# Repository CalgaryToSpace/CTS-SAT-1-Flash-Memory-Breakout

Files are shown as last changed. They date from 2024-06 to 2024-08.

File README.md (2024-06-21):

# CTS-SAT-1-Flash-Memory-Breakout

A breakout board for the CTS-SAT-1 flash memory module, used on the Onboard Computer (OBC) of the CTS-SAT-1 satellite.

The target memory modules is the `S70FL01GSAGMFI011` (`S70FL01`). This PCB is compatible with many similar memory modules in the same family.

This PCB is pin-compatible with the following memory modules:
* Infineon `S70FL01GSAGMFI011` (`S70FL01`)
* Infineon `S25FL512SDVFG1` (`S25FL512`)
* Cypress `25HL01GTFI01` (`25HL01`)

## PCB Renderings

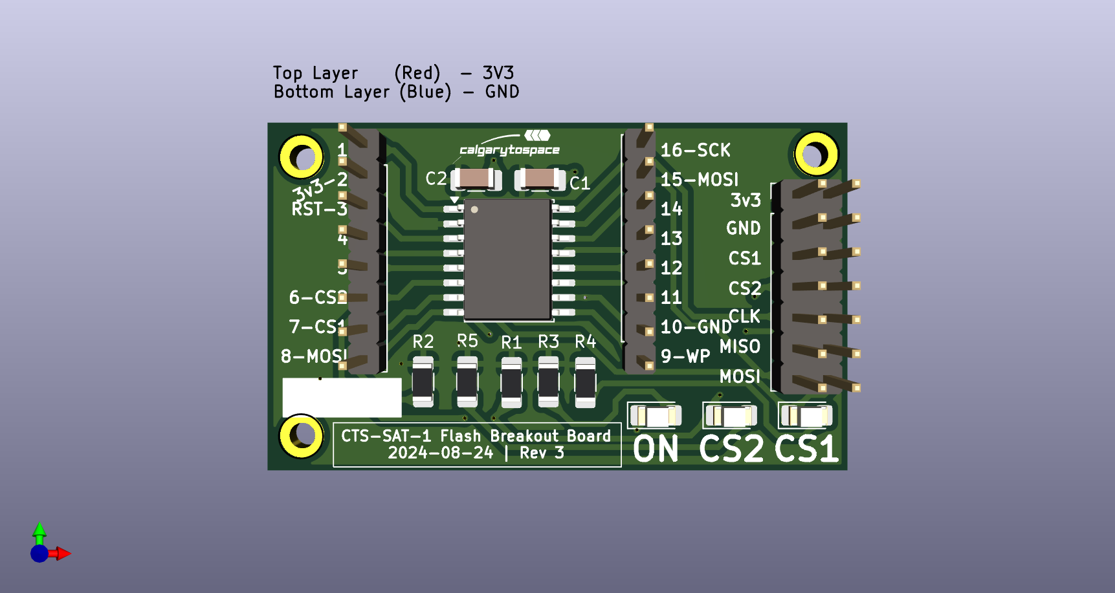
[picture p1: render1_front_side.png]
Front Rendering


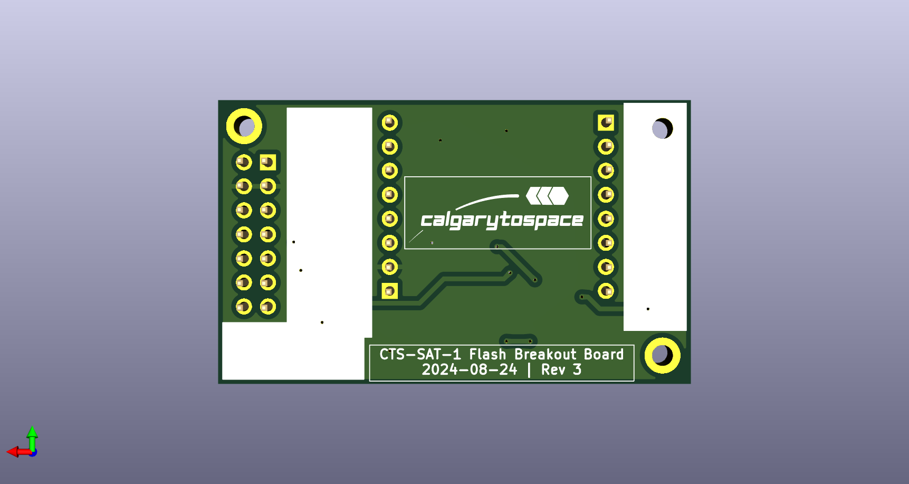
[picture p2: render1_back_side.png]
Back Rendering


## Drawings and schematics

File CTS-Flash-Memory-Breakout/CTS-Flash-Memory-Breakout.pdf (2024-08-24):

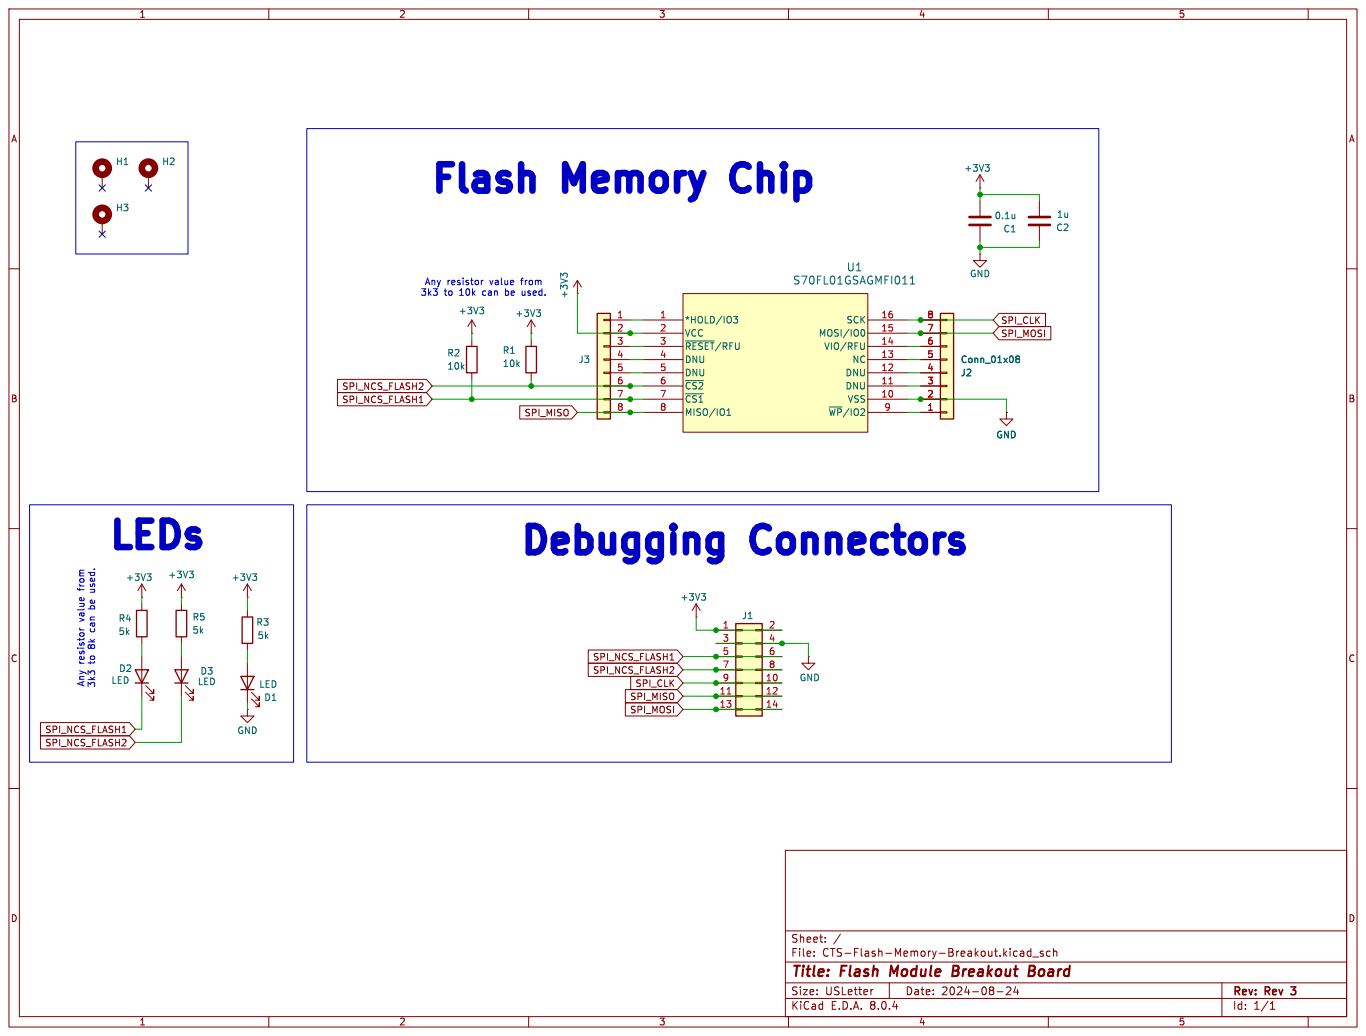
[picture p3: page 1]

2 | 7 7
3 | 6 6
4 | 5 5
5 | 4 4
6 | 3 3
7 | 2 2
8 | 1 1

SPI_NCS_FLASH2 SPI_NCS_FLASH2 SPI_NCS_FLASH1 Any resistor value from 3k3 to 8k can be used.

File: CTS-Flash-Memory-Breakout.kicad_sch Sheet: / GND

Id: 1/1 Title: Flash Module Breakout Board

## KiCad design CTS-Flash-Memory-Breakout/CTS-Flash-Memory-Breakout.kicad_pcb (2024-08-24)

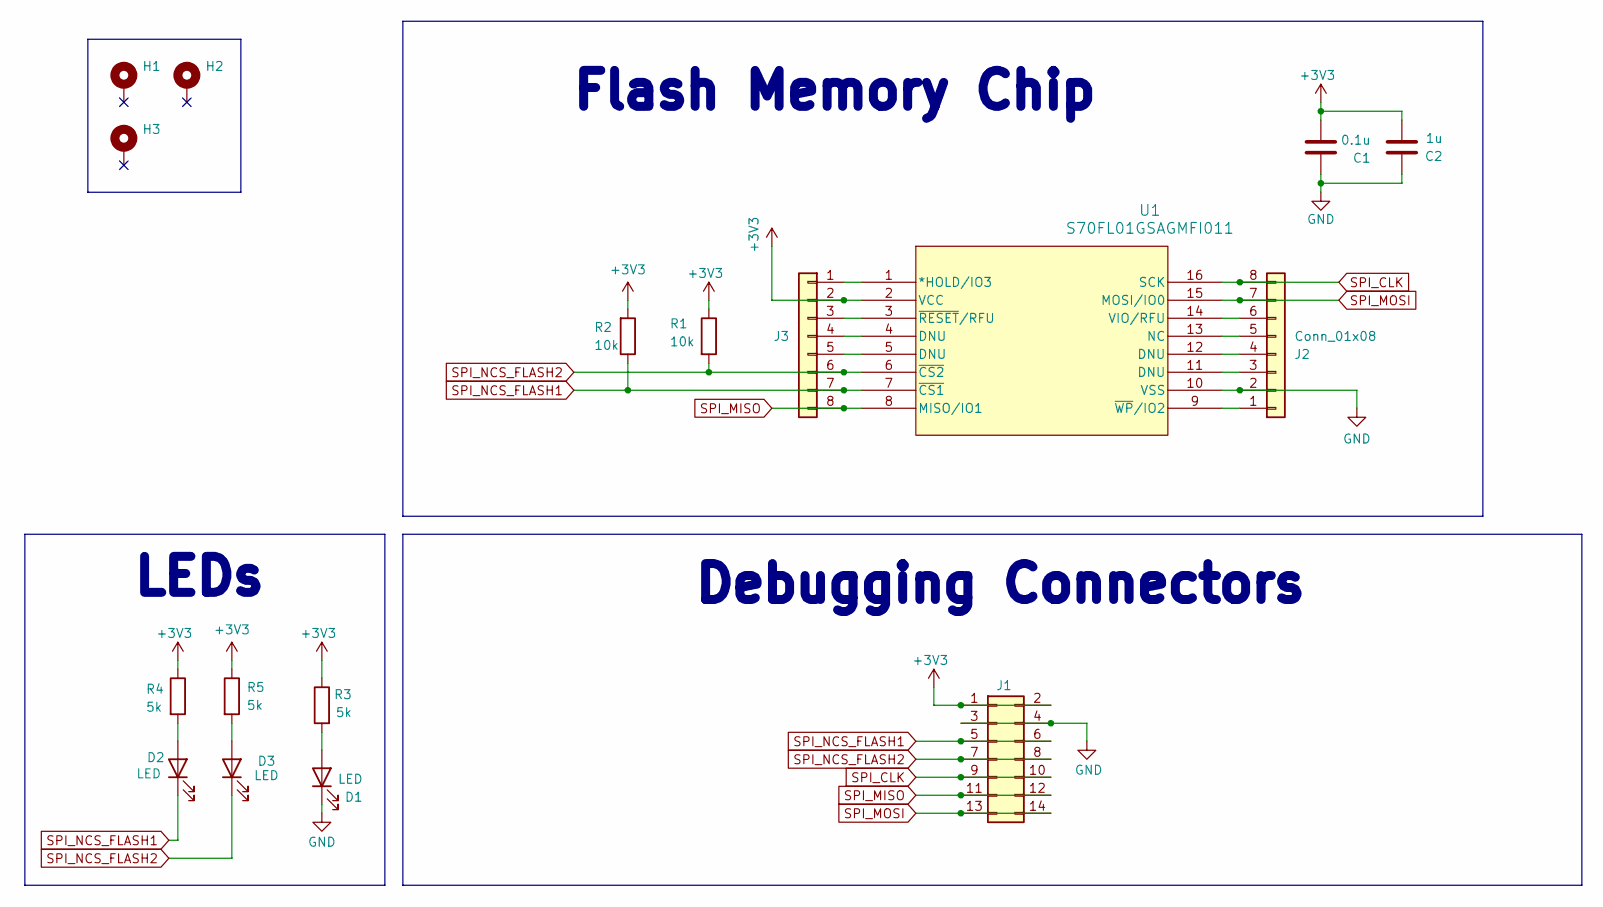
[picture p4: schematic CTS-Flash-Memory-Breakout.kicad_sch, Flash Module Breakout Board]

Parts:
C1: 0.1u; C_1206_3216Metric_Pad1.33x1.80mm_HandSolder
C2: 1u; C_1206_3216Metric_Pad1.33x1.80mm_HandSolder
D1, D2, D3: LED; LED_1206_3216Metric_Pad1.42x1.75mm_HandSolder
H1, H2, H3: MountingHole_Pad; MountingHole_2.2mm_M2_DIN965_Pad
J1: Conn_02x07_Counter_Clockwise; PinHeader_2x07_P2.54mm_Vertical
J2, J3: Conn_01x08; PinHeader_1x08_P2.54mm_Vertical
R1, R2: 10k; R_1206_3216Metric_Pad1.30x1.75mm_HandSolder
R3, R4, R5: 5k; R_1206_3216Metric_Pad1.30x1.75mm_HandSolder
U1: S70FL01GSAGMFI011; SOIC-16W_7.5x10.3mm_P1.27mm

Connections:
+3V3: C1.2, C2.2, J1.1, J1.2, J3.2, R1.1, R2.2, R3.1, R4.1, R5.1, U1.2 (VCC)
GND: C1.1, C2.1, D1.1 (K), J1.3, J1.4, J2.2, U1.10 (VSS)
unnamed: D1.2 (A), R3.2
unnamed: D2.2 (A), R4.2
unnamed: D3.2 (A), R5.2
unnamed: J2.1, U1.9 (~WP/IO2)
unnamed: J2.3, U1.11 (DNU)
unnamed: J2.4, U1.12 (DNU)
unnamed: J2.5, U1.13 (NC)
unnamed: J2.6, U1.14 (VIO/RFU)
unnamed: J3.1, U1.1 (*HOLD/IO3)
unnamed: J3.3, U1.3 (~RESET/RFU)
unnamed: J3.4, U1.4 (DNU)
unnamed: J3.5, U1.5 (DNU)
SPI_CLK: J1.9, J1.10, J2.8, U1.16 (SCK)
SPI_MISO: J1.11, J1.12, J3.8, U1.8 (MISO/IO1)
SPI_MOSI: J1.13, J1.14, J2.7, U1.15 (MOSI/IO0)
SPI_NCS_FLASH1: D2.1 (K), J1.5, J1.6, J3.7, R2.1, U1.7 (~CS1)
SPI_NCS_FLASH2: D3.1 (K), J1.7, J1.8, J3.6, R1.2, U1.6 (~CS2)

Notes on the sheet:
LEDs
Debugging Connectors
Flash Memory Chip

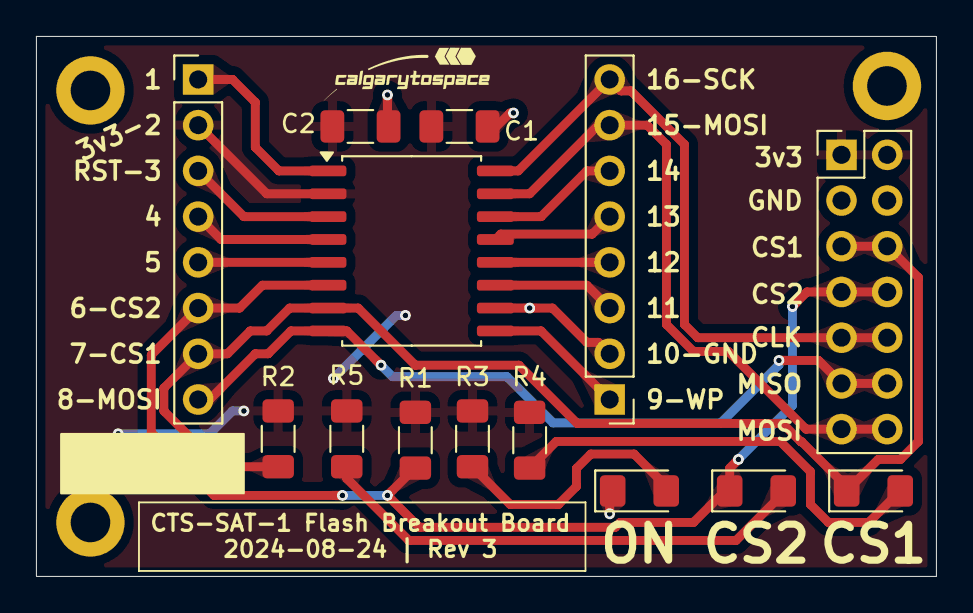
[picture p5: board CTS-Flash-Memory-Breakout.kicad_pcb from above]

Board: 2 copper layers, 50.0 x 30.0 mm, 17 parts (0 on the bottom side), 19 nets.

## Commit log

2024-05-08 Created project
    Created project and added CAD files to repository
    [CTS-Flash-Memory-Breakout.kicad_pcb, CTS-Flash-Memory-Breakout.kicad_sch]
2024-05-08 Silkscreen modifications
    Added CTS logo to board alongside date and revision #
    [CTS-Flash-Memory-Breakout.kicad_pcb]
2024-05-08 Created production files
    Created production files
    [CTS-Flash-Memory-Breakout.kicad_pcb]
2024-06-07 Update errata on schematic, add rendering and part number to README
    [CTS-Flash-Memory-Breakout.kicad_sch]
2024-06-08 Create Rev 2 board
    - Breakout every pin on the chip to new headers
    - Fix missing inline resistors for LEDs
    - Add extra bulk capacitance
    - Reroute with wide traces
    - More silkscreens
    - Silkscreens for writing notes/labels in Sharpie
    [CTS-Flash-Memory-Breakout.kicad_pcb, CTS-Flash-Memory-Breakout.kicad_sch]
2024-06-21 Create Rev 2
    - Add mounting holes
    - Improve routing
    [CTS-Flash-Memory-Breakout.kicad_pcb, CTS-Flash-Memory-Breakout.kicad_sch]
2024-08-24 Create Rev 3 with CS label fix, teardrops
    Changes from Rev 2:
    * Fixed bad CS0/CS1 label to CS1/CS2.
    * Added teardrops
    * Fixed some routing to move traces farther from pads
    [CTS-Flash-Memory-Breakout.kicad_pcb, CTS-Flash-Memory-Breakout.kicad_sch]
2024-08-24 Re-plot Rev 3 schematic
    [CTS-Flash-Memory-Breakout.kicad_sch]
